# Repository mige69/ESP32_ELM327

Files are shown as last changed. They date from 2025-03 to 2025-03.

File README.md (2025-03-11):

# ESP32_ELM327
ELM327 emulator with an ESP32

Bluetooth function

OTA update function for a period of 10 minutes after power on

Apk file to android phone for suzuki bike work with ESP32_ELM327 (file work with elm327 with pic18f25k80)

folder eagle schematic

https://www.youtube.com/watch?v=ZsCw8m0fg5I

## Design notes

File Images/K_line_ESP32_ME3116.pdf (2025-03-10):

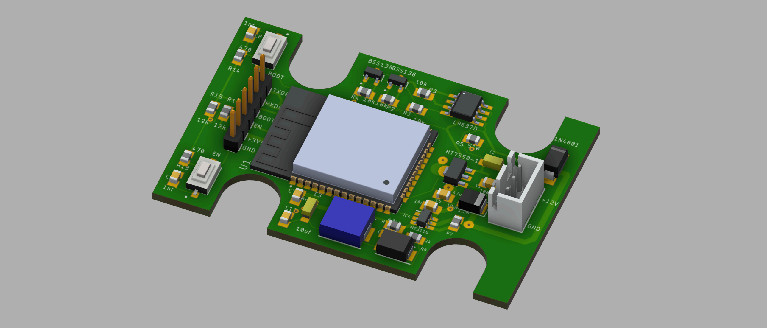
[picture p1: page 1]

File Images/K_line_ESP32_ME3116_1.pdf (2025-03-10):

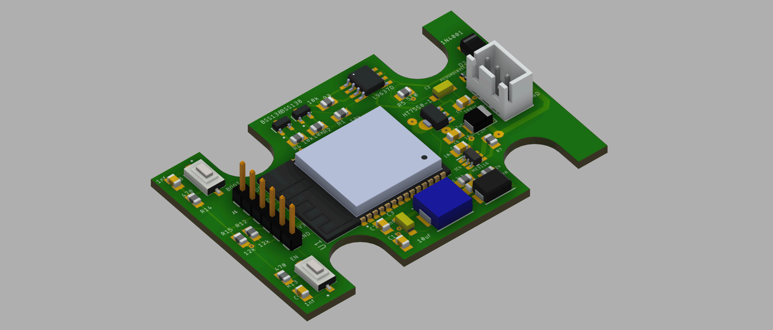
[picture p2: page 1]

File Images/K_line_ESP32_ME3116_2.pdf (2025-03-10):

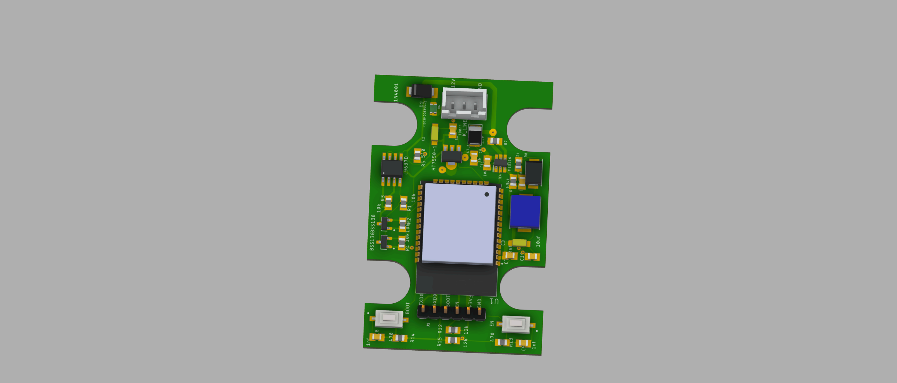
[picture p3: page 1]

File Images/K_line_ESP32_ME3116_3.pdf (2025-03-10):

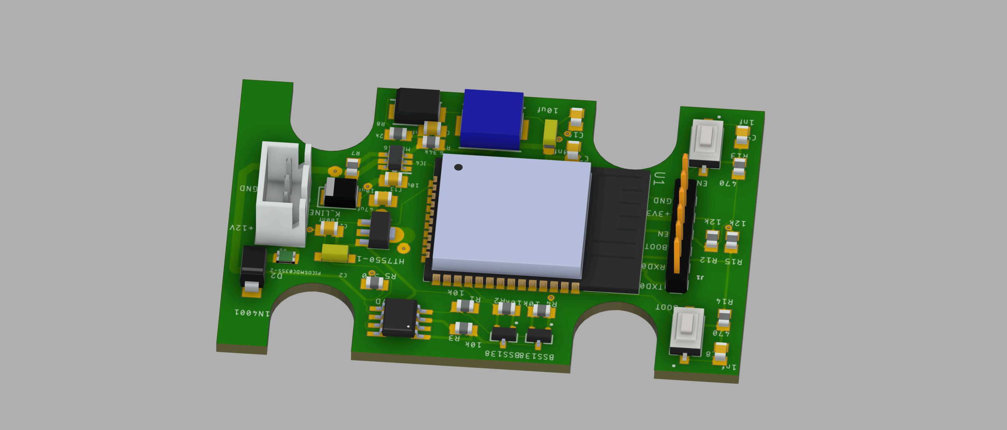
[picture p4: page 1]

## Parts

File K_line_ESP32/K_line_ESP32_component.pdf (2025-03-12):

Feuille1

Part
1.2M,R7,R0805,
1N4001,D2,DO214AA,
1nf,C8 | C9,C0805K,
2k,R8,R0805,
6.34k,R9,R0805,
10k,R1 | R2
10uf,C2 | C3,CT3216,
10uf,C6 | C11,C0805K,
10uh,L1,INDPM7366X300N,
12k,R12 | R15,R0805,
47uf,C4,CAPMP3528X210N,
100nf,C1 | C7
470,R13 | R14,R0805,
470nf,C12,C0805K,
510,R5,R0805,
BSS138,Q1 | Q2,SOT95P240X111-3N,
ESP32-WROOM-32,U1,MODULE_ESP32-WROOM-32, HT7550-1,IC3,SOT89,
L9637D,IC1,SO08,
ME3116,IC4,SOT95P270X145-6N,
PICOSMDC035S-2,R6,RESC2012X65N,
SS24,D3,DIOM5436X247N,
TS09-63-25-R-260-SMT-TR,S1 | S2,SW_TS09-63-25-R-260-SMT-TR,

Comment,Designator,Footprint,LCSC

Feuille1

R3 | R4,R0805,

C10,C0805K,

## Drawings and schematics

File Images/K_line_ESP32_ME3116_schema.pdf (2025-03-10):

10/03/2025 13:49 C:\Users\migue\OneDrive\Documents\EAGLE\projects\K_line_ESP32\K_line_ESP32.sch (Sheet: 1/2) | SpiceOrder 1 SpiceOrder 2

A

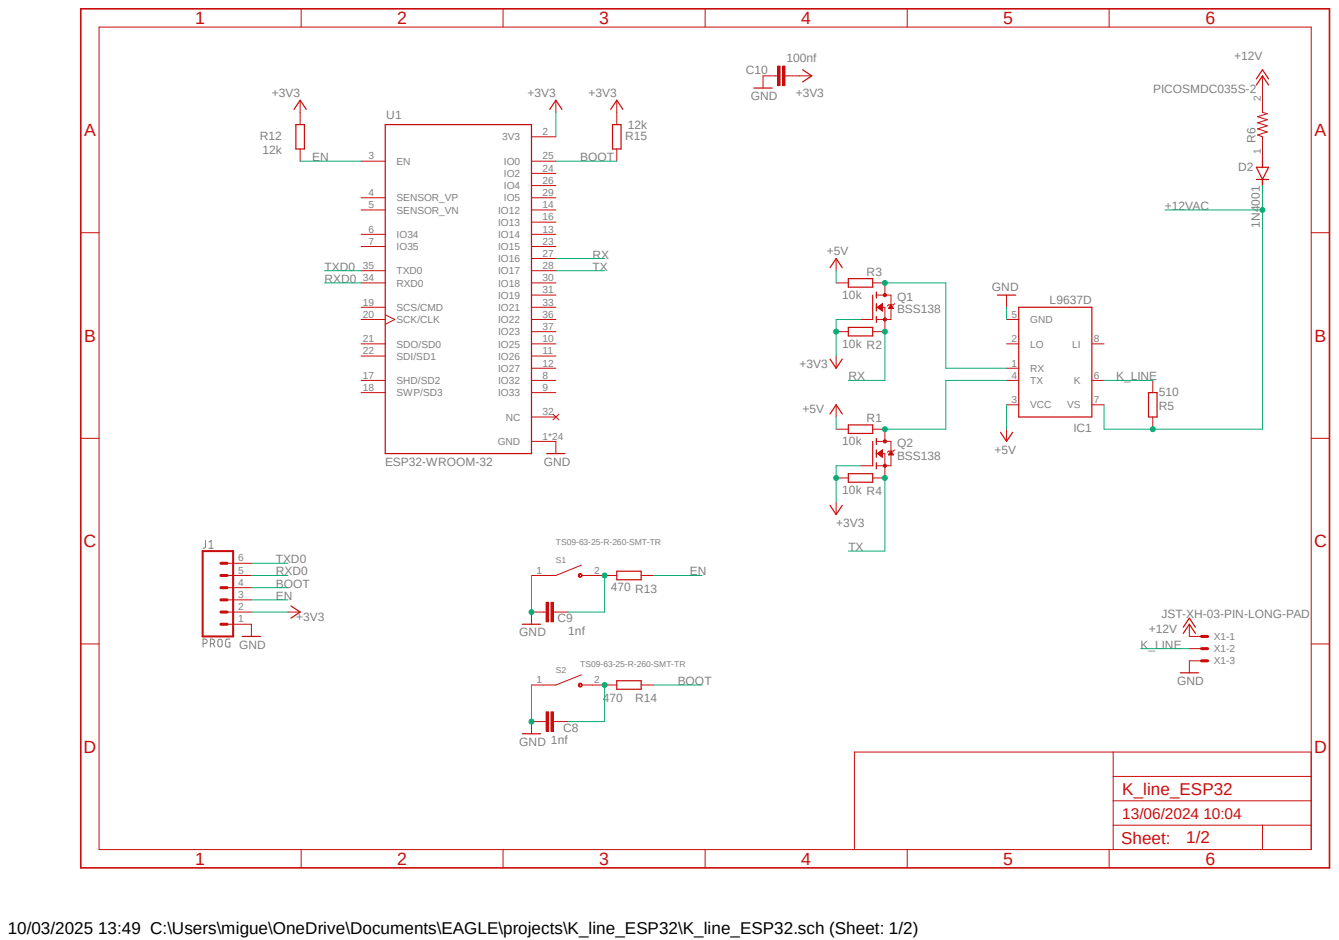
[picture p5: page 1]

10uf | +5V
C3 | C7 VIN 2*2 GND

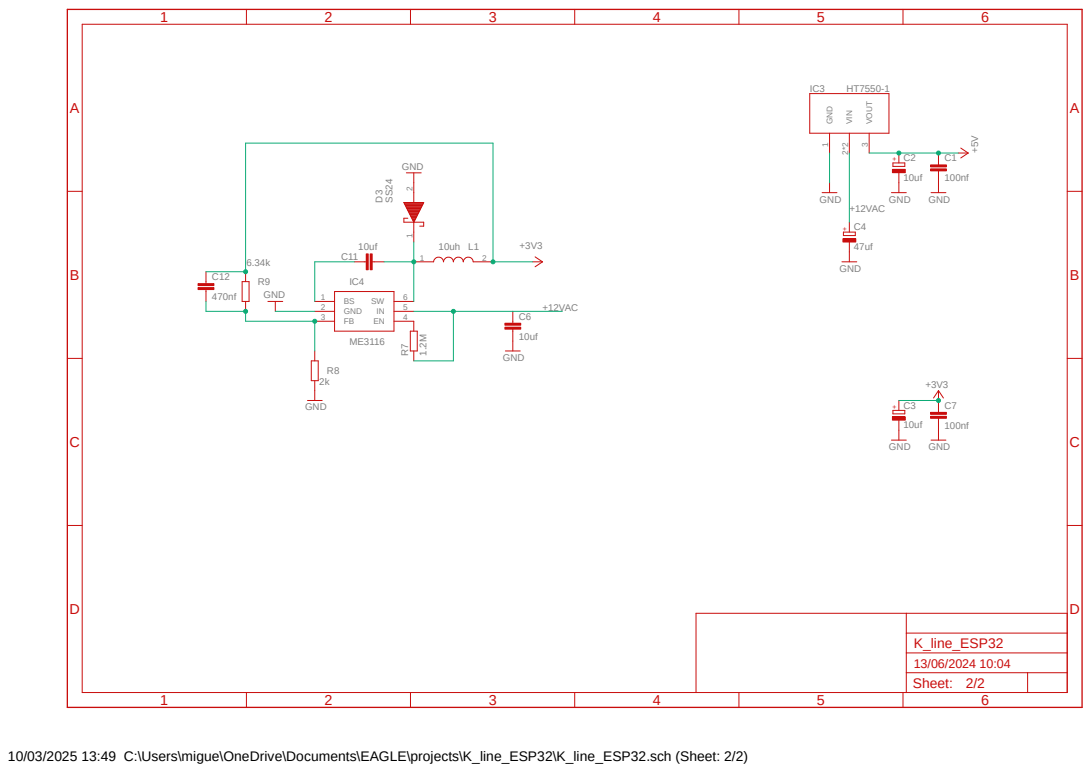
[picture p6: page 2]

10/03/2025 13:49 C:\Users\migue\OneDrive\Documents\EAGLE\projects\K_line_ESP32\K_line_ESP32.sch (Sheet: 2/2)

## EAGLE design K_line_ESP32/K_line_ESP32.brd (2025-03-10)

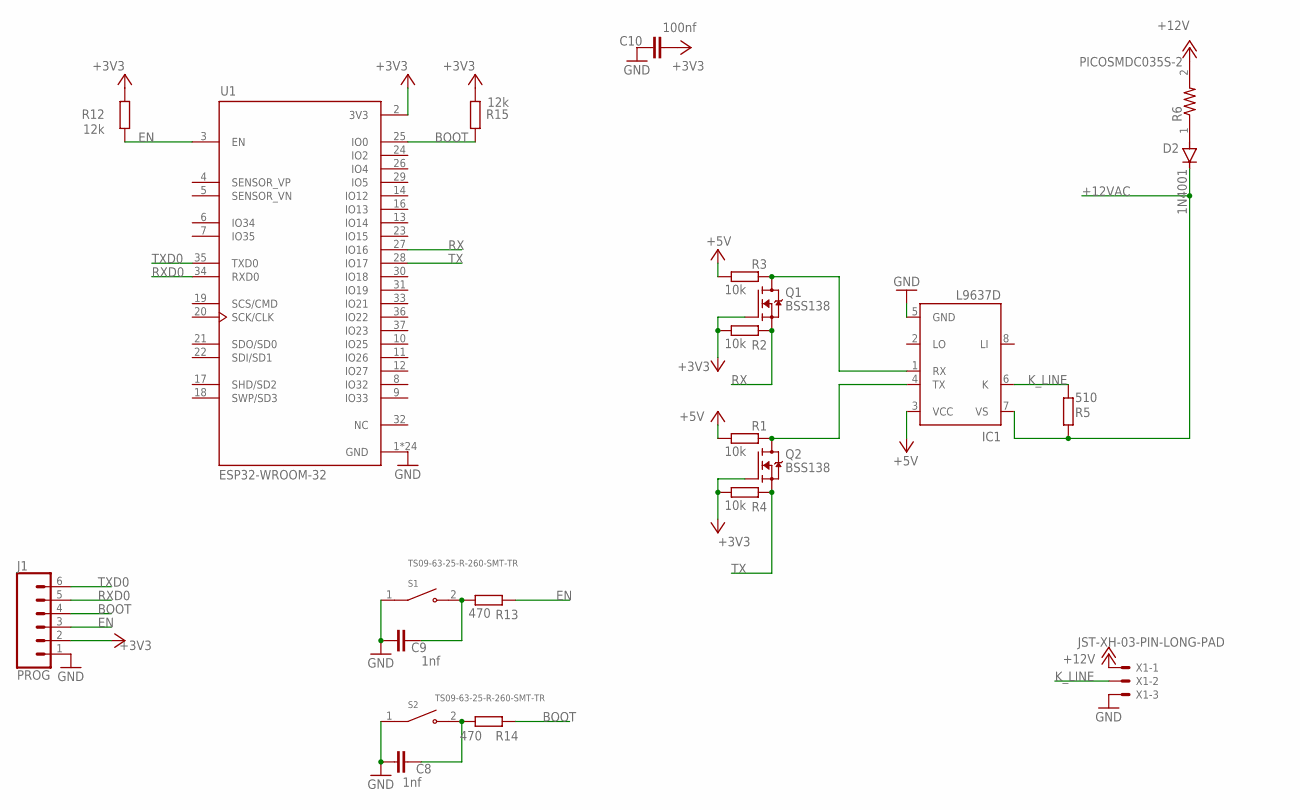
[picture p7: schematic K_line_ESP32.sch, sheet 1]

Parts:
C8, C9: 1nf; C0805K
C10: 100nf; C0805K
D2: 1N4001; DO214AA
IC1: L9637D; SO08
J1: PROG; 1X06
Q1, Q2: BSS138; SOT95P240X111-3N
R1, R2, R3, R4: 10k; R0805
R5: 510; R0805
R6: PICOSMDC035S-2; RESC2012X65N
R12, R15: 12k; R0805
R13, R14: 470; R0805
S1, S2: TS09-63-25-R-260-SMT-TR; SW_TS09-63-25-R-260-SMT-TR
U1: ESP32-WROOM-32; MODULE_ESP32-WROOM-32
X1: JST-XH-03-PIN-LONG-PAD; JST-XH-03-PACKAGE-LONG-PAD

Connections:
+3V3: C10.2, J1.2, Q1.1 (G), Q2.1 (G), R2.1, R4.1, R12.2, R15.2, U1.2 (3V3); also elsewhere on the board
+5V: IC1.3 (VCC), R1.1, R3.1; also elsewhere on the board
+12V: R6.2, X1.1
+12VAC: D2.C, IC1.7 (VS), R5.2; also elsewhere on the board
BOOT: J1.4, R14.1, R15.1, U1.25 (IO0)
EN: J1.3, R12.1, R13.1, U1.3 (EN)
GND: C8.2, C9.1, C10.1, IC1.5 (GND), J1.1, S1.1, S2.1, U1.1 (GND), U1.15 (GND), U1.38 (GND), U1.39_1 (GND), U1.39_2 (GND), U1.39_3 (GND), U1.39_4 (GND), U1.39_5 (GND), U1.39_6 (GND), U1.39_7 (GND), U1.39_8 (GND), U1.39_9 (GND), U1.39_10 (GND), U1.39_11 (GND), U1.39_12 (GND), U1.39_13 (GND), U1.39_14 (GND), U1.39_15 (GND), U1.39_16 (GND), U1.39_17 (GND), U1.39_18 (GND), U1.39_19 (GND), U1.39_20 (GND), U1.39_21 (GND), X1.3; also elsewhere on the board
K_LINE: IC1.6 (K), R5.1, X1.2
unnamed: IC1.1 (RX), Q1.3 (D), R3.2
unnamed: IC1.4 (TX), Q2.3 (D), R1.2
unnamed: D2.A, R6.1
unnamed: C8.1, R14.2, S2.2
unnamed: C9.2, R13.2, S1.2
RX: Q1.2 (S), R2.2, U1.27 (IO16)
RXD0: J1.5, U1.34 (RXD0)
TX: Q2.2 (S), R4.2, U1.28 (IO17)
TXD0: J1.6, U1.35 (TXD0)

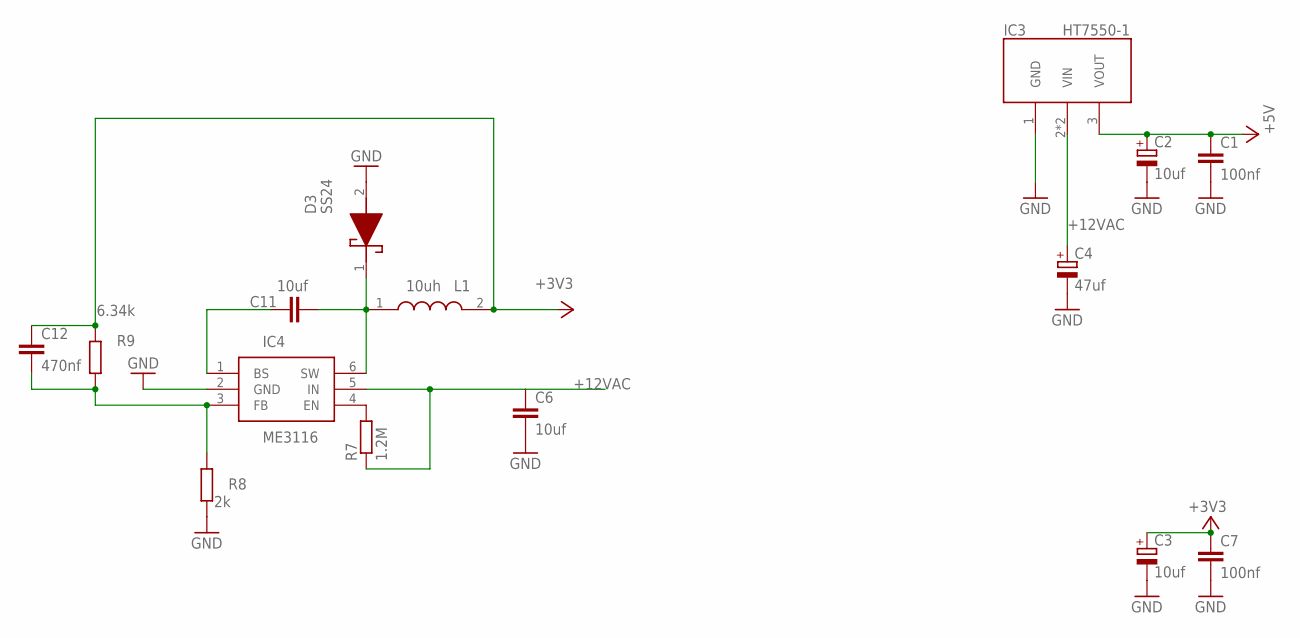
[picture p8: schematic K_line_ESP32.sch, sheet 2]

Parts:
C1, C7: 100nf; C0805K
C2, C3: 10uf; CT3216
C4: 47uf; CAPMP3528X210N
C6, C11: 10uf; C0805K
C12: 470nf; C0805K
D3: SS24; DIOM5436X247N
IC3: HT7550-1; SOT89
IC4: ME3116; SOT95P270X145-6N
L1: 10uh; INDPM7366X300N
R7: 1.2M; R0805
R8: 2k; R0805
R9: 6.34k; R0805

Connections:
+3V3: C3.+, C7.1, C12.1, L1.2, R9.2; also elsewhere on the board
+5V: C1.1, C2.+, IC3.3 (VOUT); also elsewhere on the board
+12VAC: C4.1 (+), C6.1, IC3.2 (VIN), IC3.2@1 (VIN), IC4.5 (IN), R7.1; also elsewhere on the board
GND: C1.2, C2.-, C3.-, C4.2 (-), C6.2, C7.2, D3.2 (A), IC3.1 (GND), IC4.2 (GND), R8.1; also elsewhere on the board
unnamed: IC4.4 (EN), R7.2
unnamed: C11.2, D3.1 (K), IC4.6 (SW), L1.1
unnamed: C11.1, IC4.1 (BS)
unnamed: C12.2, IC4.3 (FB), R8.2, R9.1

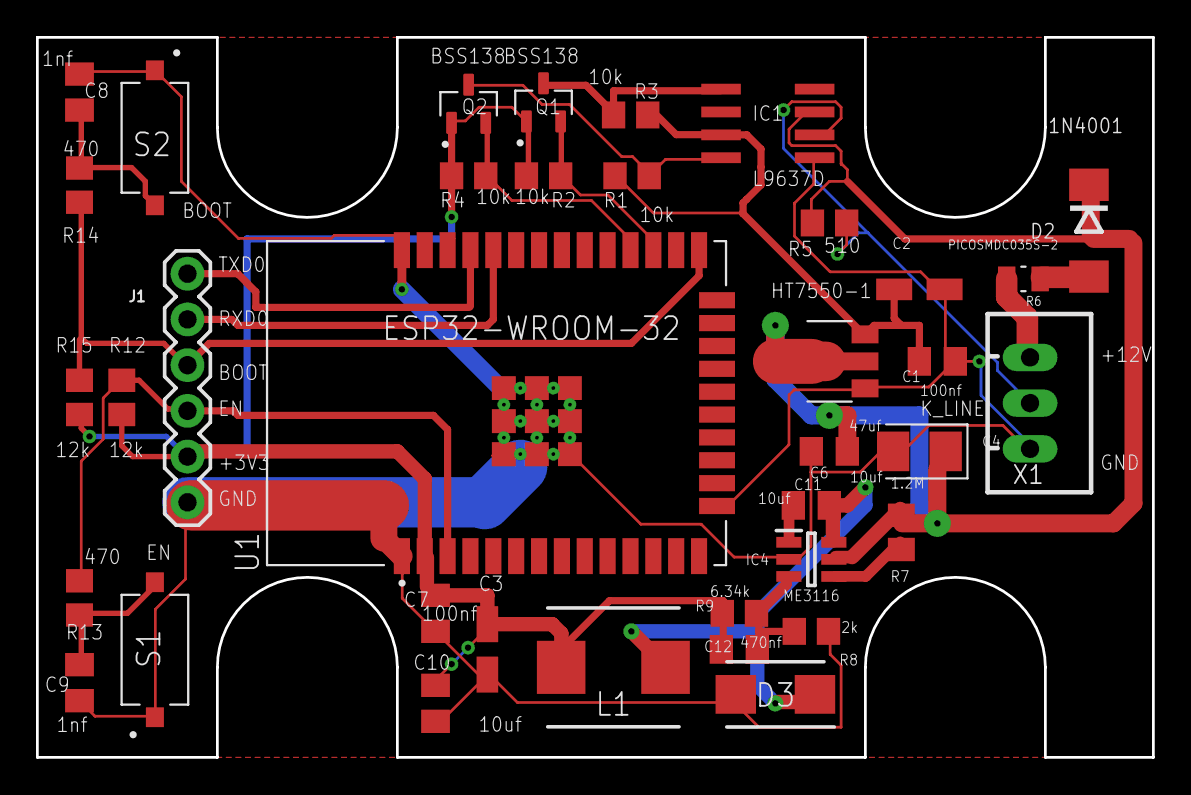
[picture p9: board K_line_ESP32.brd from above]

Board: 2 copper layers, 62.0 x 40.0 mm, 37 parts (0 on the bottom side), 21 nets.

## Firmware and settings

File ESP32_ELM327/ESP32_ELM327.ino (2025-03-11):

// This example code is in the Public Domain (or CC0 licensed, at your option.)
// By Evandro Copercini - 2018
//
// This example creates a bridge between Serial and Classical Bluetooth (SPP)
// and also demonstrate that SerialBT have the same functionalities of a normal Serial
// Note: Pairing is authenticated automatically by this device

#include <WiFi.h>
#include <WiFiAP.h>
#include <WebServer.h>
#include <ESP2SOTA.h>

#include "BluetoothSerial.h"
#include <Streaming.h>


const char* ssid = "ESP32_ELM327_OTA";
const char* password = "123456789abc";
WebServer server(80);

#define K_LINE Serial2
#define RxKline 16
#define TxKline 17

uint16_t BAUDERADE = 48000;

const unsigned long TIME_INTERVAL_KLINE = 135;
unsigned long previousMillis;
unsigned long previousMillisKline;
unsigned long previousMillisupdate;

byte const startinit[5] = { 0x81, 0x12, 0xF1, 0x81, 0x05 };

byte monitorsensordata[7] = { 0x80, 0x12, 0xF1, 0x02, 0x21, 0x08, 0xAE };

const byte buffSize = 128;  //255
char lineOne[buffSize];
int line1count;

char buffer[] = {};
char buffer_hex[] = {};
char buff_keep_alive_kline[] = {};

byte hex[] = {};
byte hex_recoit[] = {};
byte buff_envoi[] = {};
byte buff_recoit[133] = {};
byte buff_envoi_BT[] = {};
byte buff_alive_kline[6] = {};
byte buff_alive_kline_trame[] = {};


byte count = 0;
byte checksum_ok = 0;

byte format = 0x80;
byte format_init = 0x81;
byte ecuadrr = 0x12;
byte testaddr = 0xF1;
byte bus_init = 0xC1;
byte checksum_result = 0;
byte result = 0;
byte rec_hex = 0;
byte keep_alive = 0x3E;
byte keep_alive_somme = 0x01;

bool monitor = false;
String sub_hex = "";
bool check = false;
bool format_ok = false;
bool testformat_ok = false;
bool ecuadrr_ok = false;
bool envoi_ok = false;
bool recoit_ok = false;
bool testaddr_ok = false;
bool bool_alive_kline = false;
bool bool_alive_kline_ok = false;
bool init_fast = false;
bool init_slow = false;
bool bool_init_bike_honda = false;
bool init_atiia = false;
bool init_atsh = false;
bool init_atfi = false;
bool trame_kline = false;
bool mode_kline = false;
bool bool_start = false;
bool bool_init_bus = false;
bool bool_delay_fast_init_1A = false;
bool bool_delay_fast_init_1B = false;
bool bool_delay_fast_init_1A_ON = false;
bool bool_delay_fast_init_1B_ON = false;
bool bool_checksum_modulo_256 = true;
bool bool_checksum_modulo_100 = false;
bool bool_bike_honda = false;
bool bool_header_byte = true;
bool bool_trame_ok = false;
bool bool_trame_keep_alive = false;
bool bool_init_trame_keep_alive = false;
bool bool_stop_wifi = false;
bool bool_format = false;




String device_name = "ESP32_ELM327";


// Check if Bluetooth is available
#if !defined(CONFIG_BT_ENABLED) || !defined(CONFIG_BLUEDROID_ENABLED)
#error Bluetooth is not enabled! Please run `make menuconfig` to and enable it
#endif

// Check Serial Port Profile
#if !defined(CONFIG_BT_SPP_ENABLED)
#error Serial Port Profile for Bluetooth is not available or not enabled. It is only available for the ESP32 chip.
#endif

BluetoothSerial SerialBT;



const String VERSION = "ESP32_ELM327";

String value0x = "0x";

String INTERPRETATION;
String at_command = "";


const String AT = "AT";    // Echo off/on
const String ATE = "ATE";  // Echo off/on
const String ATI = "ATI";  // Version id
const String ATZ = "ATZ";  // Reset harware
const String ATS = "ATS";  // Set protocol X
const String ATH = "ATH";  // Headers off / on
const String ATL = "ATL";  // Linefeeds off/on
const String ATM = "ATM";  // Memory off/on
const String ATDPN = "ATDPN";
const String ATDESC = "AT@1";
const String ATAT = "ATAT";

const String ATIIA = "ATIIA";    // INIT Adress
const String ATIB10 = "ATIB10";  // BAUDE 10400
const String ATIB48 = "ATIB48";  // BAUDE 4800
const String ATIB96 = "ATIB96";  // BAUDE 9600
const String ATSH = "ATSH";      // EN TETE
const String ATSP = "ATSP";      // PROTOCOLE
const String ATW = "ATW";
const String ATWS = "ATWS";  // reset logiciel
const String ATSP3 = "ATSP3";
const String ATSP4 = "ATSP4";
const String ATSP5 = "ATSP5";
const String ATSPH = "ATSPH";
const String ATPP = "ATPP";
const String ATPPS = "ATPPS";
const String ATMODU = "ATMODU";
const String ATFI = "ATFI";
const String ATSW = "ATSW";  //time keep alive
const String ATWM = "ATWM";  //trame keep alive
const String PROMPT = ">";
const String LF = "\n";
const String LR = "\r";  // REPEAT LAST COMMAND
//const String OK = "OK";


String sub_ATPPS = "";
String sub_ATPPS_sub = "";
String sub_ATPPS_1A = "";
String sub_ATPPS_1B = "";
String sub = "";
String sub_atsh = "";
String sub_atsh_numb = "";
String sub_concat = "";
String envoi_rep = "";
String sub_number = "";
String sub_number_add = "0";
String string_delay_fast_init = "";
String string_header = "";
String sub_ATFI = "";

int length_atsh;
int length;
int length_alive_kline;
int length_kline;
int length_BT;
int delay_fast_init_1A = 25;
int delay_fast_init_1B = 25;
int delay_fast_init_1A_on = 0;
int delay_fast_init_1B_on = 0;
int length_atwm;
int index_atpp;

unsigned long delay_keep_alive = 3000;


int mode = 0;

void setup() {
 // Serial.begin(115200);


  pinMode(TxKline, OUTPUT);


  WiFi.mode(WIFI_AP);
  WiFi.softAP(ssid, password);
  delay(1000);
  IPAddress IP = IPAddress(10, 10, 10, 1);
  IPAddress NMask = IPAddress(255, 255, 255, 0);
  WiFi.softAPConfig(IP, IP, NMask);
  IPAddress myIP = WiFi.softAPIP();
  Serial.print("AP IP address: ");
  Serial.println(myIP);

  SerialBT.begin(device_name);  //Bluetooth device name
  
  Serial.printf("The device with name \"%s\" is started.\nNow you can pair it with Bluetooth!\n", device_name.c_str());

  /* SETUP YOR WEB OWN ENTRY POINTS */
  server.on("/myurl", HTTP_GET, []() {
    server.sendHeader("Connection", "close");
    server.send(200, "text/plain", "Hello there!");
  });

  server.on("/", HTTP_GET, []() {
    server.sendHeader("Connection", "close");
    server.send(200, "text/html", "<head><meta http-equiv=\"refresh\" content=\"1;URL=/update\" /></head>");
  });




  /* INITIALIZE ESP2SOTA LIBRARY */
  ESP2SOTA.begin(&server);
  server.begin();

  previousMillis = millis();
  previousMillisKline = millis();
  previousMillisupdate = millis();
}

void loop() {

  if (!bool_stop_wifi) {
    if (millis() - previousMillisupdate >= 600000) {
      WiFi.mode(WIFI_OFF);
      Serial.println("WIFI_OFF");
      bool_stop_wifi = true;
    }
  }

  /* HANDLE UPDATE REQUESTS */
  server.handleClient();

  if (SerialBT.available()) {
    char c = SerialBT.read();
    if ((c == '\n' || c == '\r') && at_command.length() > 0) {
      at_command.toUpperCase();
      AT_COMMANDS_INT(at_command);
      at_command = "";
    } else if (c != ' ' && c != '\n' && c != '\r') {
      at_command += c;
    }
  }

  if (millis() - previousMillis >= delay_keep_alive) {
    previousMillis = millis();
    if (bool_init_bus) {
      if (bool_init_trame_keep_alive) {
        Serial.print("length_atwm = ");
        Serial.println(length_atwm);
        for (int x = 0; x <= length_atwm; x++) {
          buff_envoi[x] = buff_alive_kline_trame[x];
          length = length_atwm;
        }
        bool_alive_kline = false;
        Serial.println("");
      }
      if (bool_alive_kline) {
        length = 5;
        for (int x = 0; x <= length; x++) {
          buff_envoi[x] = buff_alive_kline[x];
        }
        bool_alive_kline_ok = true;
        bool_init_trame_keep_alive = false;
      }
      envoi_trame_kline();
    }
  }
}

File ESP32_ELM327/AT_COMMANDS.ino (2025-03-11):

void AT_COMMANDS_INT(String command) {
  Serial.println(command);


  if (command.equals(ATZ)) {
    envoi_rep = VERSION;
    envoi_reponse();
    ESP.restart();
  }

  else if (command.equals(ATI)) {
    envoi_rep = VERSION;
    envoi_reponse();
  }

  else if (command.equals(ATWS)) {
    envoi_rep = VERSION;
    envoi_reponse();
    Reset_atws();
  }

  else if (command.startsWith(ATSW)) {
    String sub_ATSW = "";
    String sub_ATSW_keep = "  ";
    String sub_ATSW_keep_alive = "";
    String sub_ATSW_keep_alive_ms = " ms ";
    sub_ATSW = command;  //ATSWFF
    length = command.length();
    length = length - 2;
    sub = command.substring(length);  //FF
    value0x = value0x + sub;
    uint8_t bin = strtol(value0x.c_str(), NULL, 0);
    delay_keep_alive = 20 * bin;
    sub_ATSW.concat(sub_ATSW_keep);
    sub_ATSW_keep_alive = String(delay_keep_alive);
    sub_ATSW.concat(sub_ATSW_keep_alive);
    sub_ATSW.concat(sub_ATSW_keep_alive_ms);
    value0x = "0x";
    envoi_rep = sub_ATSW;
    envoi_reponse();
  }

  else if (command.startsWith(ATWM)) {
    String sub_atwm = "";
    length_atwm = 4;
    sub_atwm = command.substring(length_atwm);
    length_atwm = sub_atwm.length();
    buff_keep_alive_kline[sub_atwm.length() + 1];
    sub_atwm.toCharArray(buff_keep_alive_kline, sub_atwm.length() + 1);
    length_atwm = sub_atwm.length() + 1;
    length_atwm = length_atwm / 2;
    bool_trame_keep_alive = true;
    bool_init_trame_keep_alive = true;
    hex[length_atwm];
    convert_string_hex(hex, buff_keep_alive_kline);
    envoi_rep = command;
    envoi_reponse();
  }


  else if (command.startsWith(ATH)) {
    int index_ath;
    index_ath = command.indexOf("0");
    if (index_ath > -1) {
      bool_header_byte = false;
      envoi_rep = command;
    }
    index_ath = command.indexOf("1");
    if (index_ath > -1) {
      bool_header_byte = true;
      envoi_rep = command;
    }

    envoi_reponse();
  }

  else if (command.equals(ATIB10)) {
    BAUDERADE = 10400;
    envoi_rep = BAUDERADE;
    envoi_reponse();
  }

  else if (command.equals(ATIB96)) {
    BAUDERADE = 9600;
    envoi_rep = BAUDERADE;
    envoi_reponse();
  }

  else if (command.equals(ATIB48)) {
    BAUDERADE = 4800;
    envoi_rep = BAUDERADE;
    envoi_reponse();
  }

  else if (command.startsWith(ATMODU)) {
    int index_atmodu;
    index_atmodu = command.indexOf("256");
    if (index_atmodu > -1) {
      bool_checksum_modulo_256 = true;
      bool_checksum_modulo_100 = false;
      envoi_rep = command;
    }
    index_atmodu = command.indexOf("100");
    if (index_atmodu > -1) {
      bool_checksum_modulo_256 = false;
      bool_checksum_modulo_100 = true;
      envoi_rep = command;
    }

    envoi_reponse();
  }

  else if (command.equals(ATPPS)) {
    if (bool_delay_fast_init_1A) {
      sub_ATPPS = "1A ";
    } else {
      sub_ATPPS = "1A ";
    }
    if (bool_delay_fast_init_1A_ON) {
      sub_ATPPS_sub = "ON ";
      sub_ATPPS.concat(sub_ATPPS_sub);
      sub_ATPPS_sub = String(delay_fast_init_1A_on);
      sub_ATPPS.concat(sub_ATPPS_sub);
      sub_ATPPS_sub = " ms ";
      sub_ATPPS.concat(sub_ATPPS_sub);
    } else {
      sub_ATPPS_sub = "OFF ";
      sub_ATPPS.concat(sub_ATPPS_sub);
      sub_ATPPS_sub = String(delay_fast_init_1A);
      sub_ATPPS.concat(sub_ATPPS_sub);
      sub_ATPPS_sub = " ms ";
      sub_ATPPS.concat(sub_ATPPS_sub);
    }
    if (bool_delay_fast_init_1B) {
      sub_ATPPS_sub = "1B ";
      sub_ATPPS.concat(sub_ATPPS_sub);
    } else {
      sub_ATPPS_sub = "1B ";
      sub_ATPPS.concat(sub_ATPPS_sub);
    }
    if (bool_delay_fast_init_1B_ON) {
      sub_ATPPS_sub = "ON ";
      sub_ATPPS.concat(sub_ATPPS_sub);
      sub_ATPPS_sub = String(delay_fast_init_1B_on);
      sub_ATPPS.concat(sub_ATPPS_sub);
      sub_ATPPS_sub = " ms ";
      sub_ATPPS.concat(sub_ATPPS_sub);
    } else {
      sub_ATPPS_sub = "OFF ";
      sub_ATPPS.concat(sub_ATPPS_sub);
      sub_ATPPS_sub = String(delay_fast_init_1B);
      sub_ATPPS.concat(sub_ATPPS_sub);
      sub_ATPPS_sub = " ms ";
      sub_ATPPS.concat(sub_ATPPS_sub);
    }
    envoi_rep = sub_ATPPS;
    envoi_reponse();
  }

  else if (command.equals(ATSP3)) {
    init_slow = true;
    BAUDERADE = 10400;
    envoi_rep = command;
    envoi_reponse();
  }

  else if (command.equals(ATSP4)) {
    init_slow = true;
    BAUDERADE = 10400;
    envoi_rep = command;
    envoi_reponse();
  }

  else if (command.equals(ATSP5)) {
    init_fast = true;
    BAUDERADE = 10400;
    Serial.print("init_fast");
    envoi_rep = command;
    envoi_reponse();
  }

  else if (command.equals(ATSPH)) {
    bool_init_bike_honda = true;
    bool_bike_honda = true;
    bool_checksum_modulo_256 = false;
    BAUDERADE = 10400;
    Serial.print("init_bike_honda");
    envoi_rep = command;
    envoi_reponse();
  }

  else if (command.startsWith(ATPP)) {

    index_atpp = command.indexOf("1AON");
    if (index_atpp > -1) {
      delay_fast_init_1A = delay_fast_init_1A_on;
      bool_delay_fast_init_1A_ON = true;
      envoi_rep = command;
      envoi_reponse();
    }
    index_atpp = command.indexOf("1BON");
    if (index_atpp > -1) {
      delay_fast_init_1B = delay_fast_init_1B_on;
      bool_delay_fast_init_1B_ON = true;
      envoi_rep = command;
      envoi_reponse();
    }
    index_atpp = command.indexOf("1AOFF");
    if (index_atpp > -1) {
      delay_fast_init_1A = 25;
      delay_fast_init_1A_on = 0;
      bool_delay_fast_init_1A_ON = false;
      envoi_rep = command;
      envoi_reponse();
    }
    index_atpp = command.indexOf("1BOFF");
    if (index_atpp > -1) {
      delay_fast_init_1B = 25;
      delay_fast_init_1B_on = 0;
      bool_delay_fast_init_1B_ON = false;
      envoi_rep = command;
      envoi_reponse();
    }
    index_atpp = command.indexOf("SV");
    if (index_atpp > -1) {
      index_atpp = command.indexOf("1A");
      if (index_atpp > -1) {
        string_delay_fast_init = command.substring(8);
        value0x = value0x + string_delay_fast_init;
        uint8_t bin = strtol(value0x.c_str(), NULL, 0);
        delay_fast_init_1A_on = 2.5 * bin;
        value0x = "0x";
        bool_delay_fast_init_1A = true;
        envoi_rep = command;
        envoi_reponse();
      }
      index_atpp = command.indexOf("1B");
      if (index_atpp > -1) {
        string_delay_fast_init = command.substring(8);
        value0x = value0x + string_delay_fast_init;
        uint8_t bin = strtol(value0x.c_str(), NULL, 0);
        delay_fast_init_1B_on = 2.5 * bin;
        value0x = "0x";
        bool_delay_fast_init_1B = true;
        envoi_rep = command;
        envoi_reponse();
      }
    }
  }

  else if (command.startsWith(ATIIA)) {
    length = command.length();
    length = length - 2;
    sub = command.substring(length);
    value0x = value0x + sub;
    uint8_t bin = strtol(value0x.c_str(), NULL, 0);
    value0x = "0x";
    init_atiia = true;
    envoi_rep = command;
    envoi_reponse();
  }
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

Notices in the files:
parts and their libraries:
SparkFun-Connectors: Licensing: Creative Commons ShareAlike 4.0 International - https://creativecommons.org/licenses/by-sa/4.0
